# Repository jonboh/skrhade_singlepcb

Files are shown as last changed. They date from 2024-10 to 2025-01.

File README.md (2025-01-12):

# SKRHADE010 Single PCB
These PCBs were designed to iterate on a [dactyl design mounting these switches](https://github.com/jonboh/skyl_prototype).

These switches can be acquired in [Mouser](https://eu.mouser.com/ProductDetail/688-SKRHAD) and probably other electronic component stores.

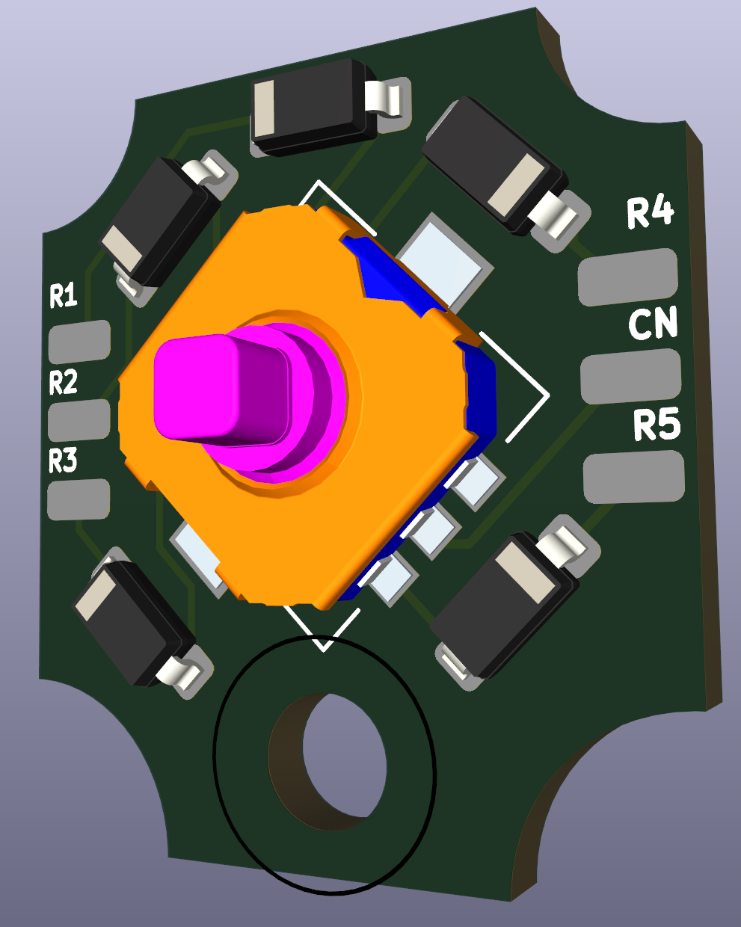
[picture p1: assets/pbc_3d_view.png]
PCB 3D View


The file [skrhade_fabrication.zip](./skrhade_fabrication.zip) can be used to
order a set of these. Note however that design i not very good, in the effort
of making the footprint as small as possible I did not realize that the wiring would be much easier
if there were pads for each point (R1, R2, R3, R4, R5, CN) on both sides. Otherwise you need a common
point for all switches. I fixed this by soldering all wires to a central point and using hot glue as
insulator.

I did not continue with the Skyl project, otherwise I would have
made the change in the design and ordered a new set.

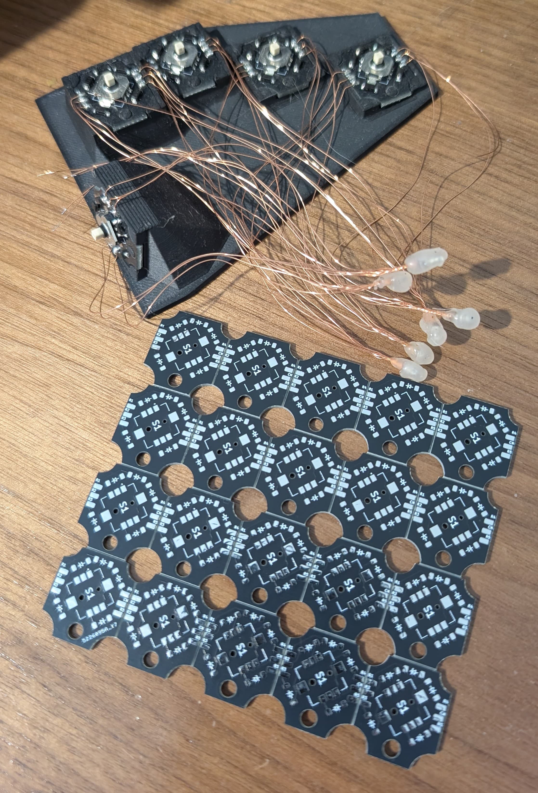
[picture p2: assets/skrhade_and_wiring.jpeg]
PCB Panel and wiring


If you want to continue with the design, I would advise adding a bit more vertical space to the PCB
and adding the missing pads of both sides, wiring will be much easier, and similar to the [single
pcbs](https://github.com/jonboh/amoeba-cherry-ulp?tab=readme-ov-file#back) used in keyboard desings with typical switches.

This project was inspired by the [harite](https://github.com/dlip/harite), I used its footprints for the single PCB.

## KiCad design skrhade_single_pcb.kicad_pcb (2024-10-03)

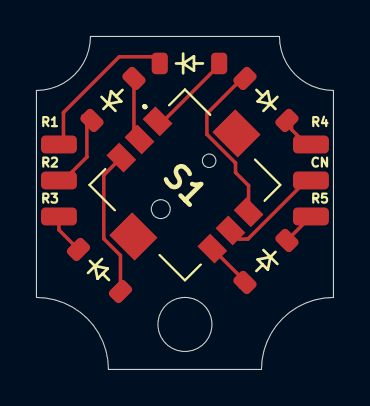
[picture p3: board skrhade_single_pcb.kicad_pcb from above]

Board: 2 copper layers, 16.5 x 18.5 mm, 12 parts (0 on the bottom side), 11 nets.

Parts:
CN: C; SolderWirePad_1x01_SMD_1x2mm
D1, D2, D3, D4, D5: D; Diode_SOD-123
R1: R1; SolderWirePad_1x01_SMD_1x2mm
R2, R3: R2; SolderWirePad_1x01_SMD_1x2mm
R4: R4; SolderWirePad_1x01_SMD_1x2mm
R5: R5; SolderWirePad_1x01_SMD_1x2mm
S1: SKRHADE010; SKRHADE

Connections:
Col N: CN.1, S1.5 (COMMON)
unnamed: D1.2 (A), S1.1 (A)
unnamed: D2.2 (A), S1.2 (CENTER)
unnamed: D3.2 (A), S1.3 (C)
unnamed: D4.2 (A), S1.4 (B)
unnamed: D5.2 (A), S1.6 (D)
Row 1: D1.1 (K), R1.1
Row 2: D2.1 (K), R2.1
Row 3: D3.1 (K), R3.1
Row 4: D4.1 (K), R4.1
Row 5: D5.1 (K), R5.1
